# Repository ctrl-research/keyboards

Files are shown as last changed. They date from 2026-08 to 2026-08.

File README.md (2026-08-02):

# keyboards
Schematics, pcbs, layout files for all my keyboard projects

## Structure

- `design/` — original keyboard designs, one folder per board with
  `layout/` (KLE, keymap, VIA), `pcb/` (KiCad), `case/` (3DP CAD), and
  `firmware/` (QMK/VIA builds) inside
  - [`gemini/`](design/gemini/) — split staggered 40% that docks into a regular 40%
- `commissions/` — VIA/layout files for boards built for others
- `docs/` — GitHub Pages site with interactive design docs, deployed by
  [`.github/workflows/pages.yml`](.github/workflows/pages.yml) on every push
  to `main` that touches `docs/` (one-time setup: Settings → Pages → Source →
  GitHub Actions)

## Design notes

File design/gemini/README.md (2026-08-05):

# Gemini

A split, row-staggered 40% whose two halves dock together to form a regular
staggered 40%. Two boards, one keyboard — hence Gemini (and it's a *mini*).

## Concept

- One Raspberry Pi Pico drives the whole board from the left half; the right
  half is passive (I/O expander) and links over a USB-C cable carrying I2C.
- Apart: a classic two-piece ergo split you can tent and shoulder-width.
- Docked: the halves mate along a staggered seam and become a conventional
  12.75u × 4u 40% (MiniVan-class footprint), visually indistinguishable from a
  one-piece board.
- The row stagger is the joint: the seam steps rightward as it descends, so the
  halves interlock like puzzle pieces instead of meeting at a straight line.

## Docked layout (12.75u × 4u)

```
|Tab  | Q | W | E | R | T ‖ Y | U | I | O | P | Bksp |
|Ctrl  | A | S | D | F | G ‖ H | J | K | L | ; | Ent |
|Shift   | Z | X | C | V | B ‖ N | M | , | . | Shift  |
|Ctl |Gui|Alt |   Space    ‖   Space   | Fn | Alt |Ctl|
```

`‖` marks the seam. Widths are approximate above; exact geometry below.

### Row geometry (units of u, x measured from left edge)

| Row | Left half | Seam x | Right half |
|-----|---|---|---|
| 1 | Tab 1.25 · Q W E R T (5×1u) | 6.25 | Y U I O P (5×1u) · Bksp 1.5 |
| 2 | Ctrl 1.5 · A S D F G (5×1u) | 6.50 | H J K L ; (5×1u) · Enter 1.25 |
| 3 | Shift 1.75 · Z X C V B (5×1u) | 6.75 | N M , . (4×1u) · Shift 2 |
| 4 | Ctrl 1.25 · GUI 1 · Alt 1.25 · Space 2.75  | 6.25 | Space 2.75 · Fn 1.25 · Alt 1.25 · Ctrl 1.25 |

Every row totals 12.75u. Standard row stagger (Tab 1.25 → Ctrl 1.5 → Shift
1.75) so the docked board reads as a normal staggered 40%.

### Seam path

Tracing the boundary of the left half from the top edge down
(coordinates in u, origin at top-left of the docked board):

```
(6.25, 0) → (6.25, 1) → (6.50, 1) → (6.50, 2) → (6.75, 2)
→ (6.75, 3) → (6.25, 3) → (6.25, 4)
```

Rows 1–3 step 0.25u right per row (following the alpha stagger); row 4 steps
back to 6.25 at the split spacebars, giving the right half a 0.5u tooth that
hooks under the left half's row 3 — a natural mechanical interlock.

The PCBs and plates are inset 1.45 mm from this boundary; the **case seam
walls** sit exactly on it and are what actually mate (with embedded
magnets) when the halves dock. See [`case/README.md`](case/README.md).

### Dimensions (1u = 19.05 mm)

| Piece | Width | Depth |
|---|---|---|
| Docked | 12.75u = 242.9 mm | 4u + 8 mm brow = 84.2 mm |
| Left half | 6.25–6.75u = 119.1–128.6 mm | 84.2 mm |
| Right half  | 6.00–6.50u = 114.3–123.8 mm | 84.2 mm |

The 8 mm rear "brow" above row 0 hosts the USB-C link ports (and the
Pico's micro-USB reach); the seam runs straight through it at 6.25u. The
key field itself stays exactly 4u deep.

(Plus case wall thickness on the non-seam edges; the seam faces should sit
flush metal-to-metal / plastic-to-plastic.)

## Split & docking mechanism (proposal)

- **Alignment**: the stepped seam self-aligns in x/y; add 2 press-fit dowel
  pins + receivers on the seam faces for z alignment.
- **Retention**: 4–6 pairs of 5×2 mm neodymium magnets embedded in the seam
  faces (polarity keyed so the halves only mate the correct way).
- **Electrical**:
  - One controller: a Raspberry Pi Pico on the left half (header-mounted on
    the back); the right half is passive with an MCP23017 I/O expander.
  - Halves link over **USB-C carrying I2C** (3V3/SDA/SCL/GND) — any USB 2.0
    C-to-C cable, orientation-proof. Works docked and split.
  - Per-key RGB: south-facing SK6812 MINI-E (reverse-mount), one 43-LED
    chain crossing the link on the cable's CC wire.
  - Stretch goal: spring-loaded pogo pins in the row-2/3 seam faces carrying
    the same signals so docking needs no cable at all.
  - Details: [`pcb/pinmap.md`](pcb/pinmap.md).

## Matrix

Both halves are electrically 4×6 (left scanned by the Pico, right read over
I2C via the expander):

| Half  | R1 | R2 | R3 | R4 |
|---|---|---|---|---|
| Left  | 6 keys | 6 keys | 6 keys | 4 keys (2 cols unused) |
| Right | 6 keys | 6 keys | 5 keys | 4 keys |

## Default keymap

See [`layout/keymap.md`](layout/keymap.md) — Base + Raise (hold right `Fn`)
+ Lower (hold left `Space`) + Adjust, MiniVan conventions, vim arrows on
`HJKL`, full 104-key coverage.

## Keycap compatibility

All sizes are standard: 1u, 1.25u, 1.5u, 1.75u, 2u, 2.75u. Notes:

- 2.75u "spacebars" are usually sold as right-Shift caps — fine in uniform
  profiles (DSA/XDA/KAT uniform); sculpted sets will have R2 shift profile.
- 1.25u Enter is a standard size but a rare legend; blanks or novelty caps.

## Project structure

- [`layout/`](layout/) — KLE layouts (docked + split, importable at
  keyboard-layout-editor.com) and the default keymap layer maps; VIA
  definition lands here too.
- [`pcb/`](pcb/) — KiCad projects for both halves.
- [`case/`](case/) — 3D-printed case CAD + STL/STEP exports.
- [`firmware/`](firmware/) — QMK keyboard definition, VIA support, built
  `.uf2` images.

## Open questions

- [ ] Split space sizes: 2.75/2.75 as drawn, or asymmetric (e.g. 2.25 + Fn on
      left thumb) for a dedicated layer key on the seam?
- [ ] Right Shift 2u vs. 1u Shift + dedicated `/` or `↑`?
- [ ] Pogo pins vs. cable-only for docked mode?
- [ ] Rotary encoder in place of a 1u mod on each half?
- [ ] Case: tray-mount 3DP first article, then CNC alu gasket for v2?

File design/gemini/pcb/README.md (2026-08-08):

# pcb

KiCad projects for the Gemini PCBs — one board per half.

**Architecture (rev A): one controller.** A single Raspberry Pi Pico on the
left half (header-mounted on the back, ~2.5 mm standoff); the right half is
passive with an MCP23017 I/O expander. The halves link over **USB-C
carrying I2C** (3V3/SDA/SCL/GND — any USB 2.0 C-to-C cable). Full pin map,
link wiring, socket-DNP keys and BOM: [`pinmap.md`](pinmap.md).

## Generated projects

- [`gemini-left/`](gemini-left/), [`gemini-right/`](gemini-right/) —
  generated `.kicad_pcb` per half: all footprints placed, nets assigned,
  seam edge cuts drawn. **Unrouted** — routing is interactive work.
- [`gemini-panel/`](gemini-panel/) — **production panel** for JLCPCB/PCBWay:
  both halves in one board, joined along their straight *outer* edges at
  x = 0 with a single **V-score** snap line (the stepped seam can't be
  V-scored — it faces outward and is routed normally). Refs and nets are
  prefixed `L_`/`R_`. Route the individual halves first, then regenerate —
  or route the panel directly and it supersedes them. When ordering: pick
  "panel by customer", 2 designs, and note "V-cut where marked" in remarks.
  Snapped V-score edges land inside the case (the seam-inset walls cover
  all board edges), so no cosmetic cleanup matters.
- Regenerate with KiCad's bundled python (wx workaround included):

  ```
  /Applications/KiCad/KiCad.app/Contents/Frameworks/Python.framework/Versions/Current/bin/python3 tools/gen_kicad_boards.py
  ```

## Inputs (source of truth: `../layout/gemini_docked.kle.json`)

- [`tools/gen_pcb_data.py`](tools/) — derives everything below from the
  layout geometry; [`tools/gen_kicad_boards.py`](tools/) builds the boards.
- [`placement/*_placement.csv`](placement/) — switch centers in mm with
  matrix row/col (per-half origin at its top-left corner).
- [`placement/*_outline.csv`](placement/) — Edge.Cuts vertices in mm
  including the stepped docking seam (inset 1.45 mm from the key boundary —
  the case seam wall carries the true boundary) and the 8 mm rear brow
  (link ports live there). Left ≤ 127.14 × 84.2 mm, right ≤ 122.38 × 84.2 mm.
- [`kbplacer/*_matrix.kle.json`](kbplacer/) — KLE annotated with `row,col`
  legends for the [kbplacer](https://github.com/adamws/kicad-kbplacer)
  plugin.
- [`lib/gemini.pretty`](lib/) — vendored footprints (marbastlib hotswap +
  stabs, Pico, HRO USB-C, MCP23017/passives from KiCad stock) and 3D
  models; licenses in `lib/licenses/`.
- [`gemini.kicad_mod`](gemini.kicad_mod) — source logo artwork from
  bitmap2component (35.9 × 13.9 mm). [`tools/gen_logo_fp.py`](tools/)
  scales it to 6 mm tall and writes `lib/gemini.pretty/Logo_Gemini.kicad_mod`
  with its origin at the artwork centre; the board generator places that
  on **F.SilkS**, centred in the 8 mm rear brow (left x 58.81, right
  x 62.29, both at y −4). The brow's *back* face is full of ports and
  passives, so the front face is where the room is. 6 mm is the practical
  floor for the small "by: j6n" glyphs: it keeps the thinnest stroke at
  0.40 mm and the tightest enclosed counter at 0.22 mm, versus the
  0.15 mm silkscreen minimum JLCPCB/PCBWay quote.

## 3D exports

The docs page's **3D model tab** (`docs/gemini/#model`) renders the full
assembly — boards + case pieces, docked/split and exploded/assembled
(three.js; GLBs live in `docs/gemini/3d/`). Re-export after board changes:

```
kicad-cli pcb export glb --subst-models --include-tracks --include-pads \
  --include-zones --include-silkscreen --user-origin 119.0625x0mm \
  -o raw-left.glb gemini-left/gemini-left.kicad_pcb   # right: no origin arg
npx gltfpack -i raw-left.glb -o docs/gemini/3d/gemini-left.glb -cc -mi -si 0.4 -noq
```

(The +119.0625 mm origin shift puts both halves in one docked frame.
`-noq` matters: quantized output renders at the wrong scale in the viewer.
`--include-silkscreen` costs ~4 % file size and is what makes the brow
logo and the reference designators show up in the viewer.)

## Before fab (rev A checklist)

- [x] Route both boards (autorouted + USB-C escapes rebuilt by hand: the
      generated nested stitch fenced the inner nets on B.Cu, so each link
      /host connector now fans out through 0.6/0.3 vias to F.Cu; DRC: 0
      unconnected on both halves and the panel)
- [ ] Verify HRO USB-C pad↔pin mapping against the datasheet (incl. which
      pads are CC vs SBU — the LED chain crosses on CC)
- [ ] Verify SK6812 MINI-E pad order (assumed 1=VDD 2=DOUT 3=VSS 4=DIN)
- [ ] Host port TP1/TP2 pads: bridge to Pico underside TP3 (D+) / TP2 (D−)
      — decide jumper wires vs relocating pads under the TPs for spring pins
- [ ] Series resistors on link D± so a real charger/host can't hurt anything
- [ ] QMK: cap `RGB_MATRIX_MAXIMUM_BRIGHTNESS` (~120) — 43 LEDs at full
      white would far exceed a 500 mA USB 2.0 budget
- [ ] DRC: Pico pin rows sit at y=19.7 and y=37.5, in the corridors between
      switch rows on both faces — confirm clearances after any nudges
- [ ] Confirm J1 orientation (port opening must overhang the rear edge)
- [ ] Case: ~5 mm pocket under the Pico strip (~2 mm elsewhere), rear
      cutouts for both link ports, side cutout for the Pico micro-USB

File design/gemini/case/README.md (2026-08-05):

# case

3D-printable case for both halves — three pieces per half, generated
parametrically by [`tools/gen_case.py`](tools/) (CadQuery) from the same
outline/placement CSVs as the PCBs.

## Stack-up (z from interior floor, per half)

| z (mm) | What |
|---|---|
| −3.0 … 0 | bottom case floor |
| 0 … 5.5 | component space (sockets 1.85, Pico stack ≈ 4.5) |
| 6.0 … 7.6 | PCB (floats — gasket mount, nothing screws into it) |
| 10.1 | lower gasket ledge (bottom case) |
| 11.1 … 12.6 | switch plate (1.5 mm), flange rides the gaskets |
| 11.8 | bottom-case rim / top-case joint line |
| 14.0 | upper gasket press lip (top case underside) |
| 16.5 | top-case bezel top (caps bottom out ≈ 18) |

Gasket: 1.5 mm poron strips above and below the plate's 2.5 mm perimeter
flange, on all edges **except the seam edge**.

## The seam edge (docking side)

The PCB and plate stop **1.45 mm short** of the true key-boundary seam
(`SEAM_INSET_MM` in `pcb/tools/gen_pcb_data.py`), which buys room for a
proper case wall on the joining side:

- **Bottom case**: full-height 1.2 mm seam wall whose *outer face sits
  exactly on the boundary* — the case walls, not the board edges, carry the
  stepped interlock and are what touch when docked. Below z = 4 the wall
  thickens inward to 2.45 mm to hold 4 × Ø3×2 mm magnet pockets (axis
  horizontal, z = 2); positions mirror across halves, polarity alternates
  N/S so the halves only dock in the correct alignment.
- **Plate and PCB**: recessed 1.45 mm behind the seam wall, fully covered
  from the side. No gasket on this edge (the plate flange stops).
- **Top case**: still open above the rim on the seam side of the key field
  (pressed caps sweep that space), but its rear band roofs the brow all the
  way to the seam plane — the two brow roofs meet when docked.

Docked appearance: caps keep near-normal spacing; beneath them the two
seam walls meet as a clean stepped line, ~2.4 mm of case material total.

## Pieces (× left/right)

1. **`*_bottom.stl/.step`** — floor + walls, gasket ledge, magnet pockets,
   port cutouts (host USB-C at left-rear corner L, link USB-C at seam-rear
   corner both halves, micro-USB side cutout L), BOOTSEL finger hole in the
   floor (L), M2 screw pilot bores in the wall tops.
2. **`*_plate.stl/.step`** — gasket-mount plate engineered against
   print-curl (see below): 1.5 mm clip web + 1.2 mm stiffening skirt
   (2.7 mm total), MX cutouts, stab cutouts, perimeter flange (1.5 mm, so
   the gasket stack is unchanged) with notches at the screw columns. Or fab
   flat 1.5 mm FR4/POM/alu from the STEP's top web.
3. **`*_top.stl/.step`** — bezel frame: presses the upper gaskets via its
   inner lip, slim ~2.9 mm bezel, counterbored M2 screws (4/half) from the
   top into the bottom-case wall pilots.

## Fasteners & hardware (per keyboard)

| Qty | Part |
|-----|---|
| 8 | M2 × 12 screw (top → bottom wall) |
| 8 | Ø3 × 2 mm neodymium magnet (seam, glued, alternating polarity) |
| ~1 m| 1.5 mm poron gasket strip |

## Printed plates and curl

A thin printed plate bows upward days after switches go in: every MX
switch's clips push outward on their cutout continuously, and 40+ switches
of sustained stress creep a 1.5 mm printed plate into a banana — PLA is the
worst offender. Countermeasures baked into the generator:

- **Clip web + skirt**: MX clips need exactly 1.5 mm of material to latch,
  so the plate keeps a 1.5 mm top web at nominal cutout size, backed by a
  1.2 mm skirt whose openings are relieved to 15.5 mm (clips and housing
  never touch it). ~2.7 mm effective thickness ≈ 6× the bending stiffness
  of a bare 1.5 mm plate, with zero change to how switches seat.
- **Fit tolerance**: `sw_cut` defaults to 14.2 mm because FDM holes print
  undersize. **Print `stl/plate_fit_coupon.stl` first** (three cutouts:
  14.1 / 14.2 / 14.3, engraved) in your actual plate material and
  orientation. Pick the size where a switch clicks in and holds without
  forcing — a too-tight fit is exactly what stores the curling stress. Set
  `P["sw_cut"]`, regenerate.
- **Material**: PETG minimum; ASA/ABS or PC better (higher creep
  resistance). Avoid PLA for the plate. Print flat, 5+ perimeters or 100%
  infill.

## Regenerate

```
cd design/gemini/case
.venv/bin/python tools/gen_case.py     # venv: python3.12 -m venv .venv && .venv/bin/pip install cadquery
```

## Known v0.1 limitations (iterate before committing to a print)

- Stab cutouts are simplified rectangles — replace with proper Cherry
  plate-mount profiles before a metal plate order.
- BOOTSEL hole position is approximate (module-center offset); verify
  against a real Pico.
- No dowel pins yet — magnets + the stepped-seam interlock handle alignment.
- Tenting/feet, bumpon recesses, and the docked-mode pogo idea are future.

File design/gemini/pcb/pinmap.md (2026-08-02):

# Gemini — electronics & pin map (rev A)

**One controller.** A single Raspberry Pi Pico on the **left** half; the
right half is passive with an **MCP23017 I/O expander**. The halves link
over **USB-C carrying I2C** — 4 conductors (3V3 on VBUS, SDA on D+, SCL on
D−, GND), so any USB 2.0 C-to-C cable works and orientation doesn't matter.
No split-sync firmware: the whole keyboard is one matrix, half of it read
over I2C (ErgoDox-style; QMK supports expander matrices natively).

## Left half — Raspberry Pi Pico (U1)

On the back, **horizontal, centered on the row-1 switch centerline**
(y = 28.575 mm), micro-USB (host port) exiting the **outer-left side
edge**. Its two header pin rows land at y ≈ 19.7 and 37.5 mm — near the
centers of the top-face corridors between switch housings, so the pins
protruding through the board clear the switch bodies sitting on top, and
no through-hole touches any socket pad or switch drill. Two row-1 diodes
(D10, D11) relocate into the brow to stay off the lower pin row.
**Mounted on low-profile headers (~2.5 mm standoff), not flat**: switch
pins protrude ~1.7 mm below the PCB and hotswap sockets are 1.85 mm tall,
so both clear underneath the module — every key above the Pico keeps its
hotswap socket. The case gets a ~5 mm pocket along this strip (elsewhere
~2 mm suffices) and a side cutout for the micro-USB.

| Pico pin | GPIO | Function | Notes |
|---|---|---|---|
| 1 | GP0 | I2C0 SDA | to link port D+ · 4.7 kΩ pull-up (R1) |
| 2 | GP1 | I2C0 SCL | to link port D− · 4.7 kΩ pull-up (R2) |
| 4–7 | GP2–GP5  | ROW0–ROW3 | shared row nets, left matrix |
| 9–12, 14–15 | GP6–GP11 | COL0–COL5 | left matrix (pin 13 is GND) |
| 21 | GP16 | LED data | → 74AHCT1G125 (U2) → LED chain |
| 36 | 3V3 | Logic rail | I2C pull-ups |
| 40 | VBUS | +5V | LED power + right half via link|
| 3, 8, 13, … | GND | Ground | |

Unused GPIOs break out to labeled test pads (encoder, pogo dock
detect — future).

## Host USB-C port (J2, left half, outer-left corner of the brow)

The desk-cable port, at the board's top-left corner — the link port sits at
the opposite (seam) end of the brow. Alternative to the Pico's onboard
micro-USB (mid-board at the side edge — flash/debug fallback). Proper
device-role port:

- **CC1/CC2**: separate 5.1 kΩ pulldowns (R3/R4) so C-to-C cables and hosts
  supply VBUS.
- **VBUS → VSYS** through Schottky DV1 (B5819W), diode-ORed against the
  Pico's internal VBUS→VSYS diode — safe with both cables plugged, per the
  Pico datasheet's dual-power pattern.
- **D+/D−**: the Pico exposes USB data only on underside test points, not
  the header. J2's D± route to two pads (TP1/TP2) in the brow next to the
  module's USB end — bridge to the Pico's **TP3 (D+) / TP2 (D−)** with two
  short jumper wires at assembly (or relocate the pads under the exact TP
  positions for spring pins during routing).
- Everything downstream (LEDs, link, right half) runs off **VSYS**
  (~4.7 V after the diode) — works identically from either port.

## Right half — MCP23017-E/SO (U1, SOIC-28)

| MCP pin | Signal | Function |
|---|---|---|
| 1–6 | GPB0–GPB5| COL0–COL5 (right) |
| 21–24 | GPA0–GPA3| ROW0–ROW3 (right) |
| 9 / 10  | VDD / VSS| 3V3 (from link) / GND · 100 nF (C1) |
| 12 / 13 | SCL / SDA| I2C, address 0x20 |
| 15–17 | A0–A2 | tied GND |
| 18 | /RESET | tied 3V3 |

3V3 comes from a local **MCP1700-3302** LDO (U2) fed by the 5V link, with
1 µF caps on both sides (C2/C3).

## Link port (J1 on each half — HRO TYPE-C-31-M-12)

| USB-C pins | Net | Carries |
|---|---|---|
| GND (1/12/shield) | GND | ground |
| VBUS (2/11) | +5V | power to right half + LEDs |
| D+ (A6/B6 = 6/7)  | SDA | I2C data |
| D− (A7/B7 = 5/8)  | SCL | I2C clock |
| CC + SBU (3/4/9/10) | LED_LINK | WS2812 LED chain data  |

CC1/CC2 are tied together on each board so the cable's single CC wire
carries LED data regardless of plug orientation (SBUs tied too — unwired
in USB 2.0 cables, parallel in full-featured ones, harmless either way).
⚠ **Requires a basic non-e-marked C-to-C cable** — an e-marker chip loads
the CC line. ⚠ **Not a real USB port** — label it. Verify the pad↔pin
mapping against the HRO datasheet before fab. Consider series resistors on
D± so nothing dies if someone plugs in a charger.

## Per-key RGB (south-facing)

**SK6812 MINI-E** reverse-mount, one per key, on the back at the switch's
**south LED window** (key center +5.08 mm) shining up through a plated
cutout — south-facing, so no north-facing keycap interference. Chain:
GP16 → 74AHCT1G125 level shifter (3V3→5V, U2 left) → left 22 LEDs
(row-major) → link CC wire → right 21 LEDs. One 43-LED chain in firmware —
no split RGB sync. Power: 5V from Pico VBUS; **cap brightness in QMK**
(43 × ~60 mA at full white ≈ 2.6 A — far beyond a USB 2.0 port's 500 mA;
`RGB_MATRIX_MAXIMUM_BRIGHTNESS` ≈ 120 keeps worst-case near spec).

## Matrix (COL2ROW, 1N4148W SOD-123 per key)

Left 4×6 (22 keys), right 4×6 (21 keys). Diode cathode → row.
Assignments in `kbplacer/gemini_{left,right}_matrix.kle.json`; switch
centers in `placement/`.

## Hotswap coverage

**All 43 keys are hotswap.** The link USB-C connectors live in an 8 mm rear
"brow" strip above row 0 (board depth 84.2 mm total), clear of every socket
zone; the keys above the header-mounted Pico keep their sockets thanks to
the standoff (see above).

## BOM sketch (per keyboard)

| Qty | Part |
|-----|---|
| 1 | Raspberry Pi Pico + low-profile headers  |
| 1 | MCP23017-E/SO (SOIC-28) |
| 1 | 74AHCT1G125 SOT-23-5 (LED level shift) |
| 1 | MCP1700-3302 SOT-23 (right 3V3 LDO) |
| 1 | B5819W SOD-123 Schottky (host VBUS OR) |
| 3 | HRO TYPE-C-31-M-12 USB-C receptacle |
| 2 | 5.1 kΩ 0603 (host port CC pulldowns) |
| 43  | SK6812 MINI-E (reverse mount RGB) |
| 43  | 1N4148W SOD-123 |
| 43  | Kailh MX hotswap socket |
| 2 | 4.7 kΩ 0603 (I2C pull-ups, left) |
| 1 | 100 nF 0603 + 2 × 1 µF 0603 |
| 1 | USB 2.0 C-to-C cable (link, non-e-marked)|
| 8–12| 5×2 mm neodymium magnets (case) |
| — | M2 heat-set inserts + screws (case) |

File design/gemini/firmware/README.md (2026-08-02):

# firmware

QMK keyboard definition and VIA support for Gemini.

Planned contents:

- `qmk/` — keyboard definition (`keyboard.json`, split config, default keymap
  per [`../layout/keymap.md`](../layout/keymap.md))
- `via/` — VIA definition JSON (same format as `commissions/*` files)
- Prebuilt `.uf2` per tagged release

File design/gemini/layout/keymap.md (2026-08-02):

# Gemini — default keymap (draft 2)

Design goal: **every key on a full-size (104-key) keyboard is typeable**,
and the common ones fall in comfortable places. This is the recommended
default — once the board runs QMK/VIA every layer is user-remappable.

Four layers:

| Layer  | Activation | Contents |
|---|---|---|
| Base | — | alphas, core punctuation, mods |
| Raise  | hold right `Fn` | digits, symbols, arrows, Del |
| Lower  | hold left `Space` | F-keys, nav, media, PrtSc cluster |
| Adjust | hold both (`Fn` + left `Space`) | numpad, RGB, bootloader |

Dual-role keys (QMK mod-tap / layer-tap):

| Key (base position) | Tap | Hold |
|---|---|---|
| R2 leftmost | Esc | Ctrl |
| Left Space (2.75u) | Space | Lower |
| Right `Fn` (1.25u) | — | Raise |

## Base

```
| Tab  | Q | W | E | R | T ‖ Y | U | I | O | P | Bksp |
| Esc⌃ | A | S | D | F | G ‖ H | J | K | L | ; | Ent  |
| Shift  | Z | X | C | V | B ‖ N | M | , | . | Shift |
| Ctl |Gui|Alt |  Spc/Lwr  ‖   Space  | Fn | Alt |Ctl |
```

## Raise (hold `Fn`) — digits, symbols, arrows

```
|  `   | 1 | 2 | 3 | 4 | 5 ‖ 6 | 7 | 8 | 9 | 0 | Del |
| Ctrl | - | = | [ | ] | \ ‖ ← | ↓ | ↑ | → | ' | Ent |
| Shift  |   |   |   |   |  ‖   |   |   | / | Shift |
| Ctl |Gui|Alt |   Space   ‖   Space  |(Fn)| Alt |Ctl |
```

- Digits mirror the standard number-row split (1–5 left, 6–0 right).
- Arrows vim-style on `HJKL`; `'` stays on the pinky where a 60% has it.
- `/` on `.` — so `?` is naturally `Raise+Shift+.`.
- Symbols `-=[]\` on the left home row in number-row order.

## Lower (hold left `Space`) — F-keys, nav, media

```
| F12  |F1 |F2 |F3 |F4 |F5 ‖ F6 | F7 | F8 | F9 |F10| F11 |
| Caps |Ins|PSc|SLk|Pse|   ‖ Hom|PgD |PgU |End |   | Ent  |
| Shift  |   |   |   |   |  ‖ Prv|Vo- |Vo+ |Nxt | Play  |
| Ctl |Gui|Alt | (held)    ‖   Space  | App|RGui|Ctl |
```

- F1–F10 mirror the digit positions; F11/F12 close the row ends.
- Nav cluster (Home/PgDn/PgUp/End) sits under the Raise arrows — same
  fingers, one layer over.
- Ins / PrtSc / ScrLk / Pause across the left home row.
- `App` (menu) and right `GUI` on the right thumb keys.

## Adjust (hold `Fn` + left `Space`) — numpad, board controls

```
| Boot |RGB|Hue|Sat|Val|   ‖NmLk| P7 | P8 | P9 | P- | Del  |
| Ctrl |   |   |   |   |   ‖ P/ | P4 | P5 | P6 | P+ | PEnt |
| Shift  |   |   |   |   |  ‖ P* | P1 | P2 | P3 | Shift |
| Ctl |Gui|Alt | (held)    ‖    P0    |(Fn)| P. |Ctl |
```

- Numpad digits as a 3×3 grid on `UIO`/`JKL`/`M,.` matching a real numpad;
  `P0` big on the right spacebar, `P.` beside it.
- `Boot` = QK_BOOT (flash mode) — needs three keys held plus the far
  corner, effectively impossible to hit by accident.

## Coverage audit — full-size (104-key) parity

| Full-size key group | Where it lives on Gemini |
|---|---|
| A–Z, `,` `.` `;`, Tab, Enter, Space | Base |
| Shift ×2, Ctrl ×2, Alt ×2, GUI (L) | Base |
| Esc | Base (tap of Esc/Ctrl) |
| 1–0, `` ` `` `-` `=` `[` `]` `\` `'` `/`| Raise |
| Arrows, Delete | Raise |
| F1–F12, Caps Lock | Lower |
| Ins, PrtSc, ScrLk, Pause | Lower |
| Home, End, PgUp, PgDn | Lower |
| App/Menu, GUI (R) | Lower |
| Numpad 0–9, `.` `/` `*` `-` `+`, Enter  | Adjust |
| Num Lock | Adjust |
| Media (not on 104, bonus) | Lower |

Every 104-key legend is reachable; nothing requires more than two held
keys (Adjust = both thumbs, then the target).

## Open items

- [ ] Left-hand-only shortcuts layer for mouse-in-right-hand use?
- [ ] Home-row mods as an alternate keymap once the board exists — easy to
      A/B in firmware, no hardware impact.
- [ ] Split-mode niceties: swap which thumb triggers Raise/Lower per user
      preference in VIA.

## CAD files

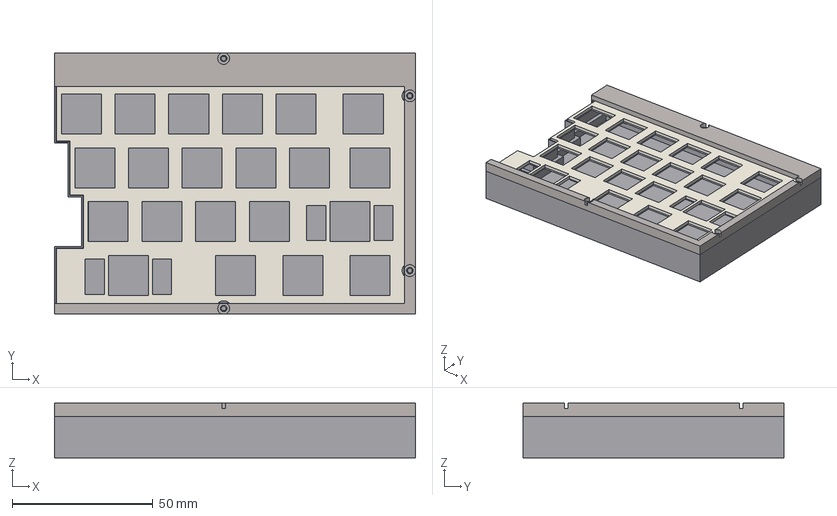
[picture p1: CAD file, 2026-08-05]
design/gemini/case/step/gemini_right_assembly.step
128.1 x 92.7 x 19.5 mm
bottom
plate
top

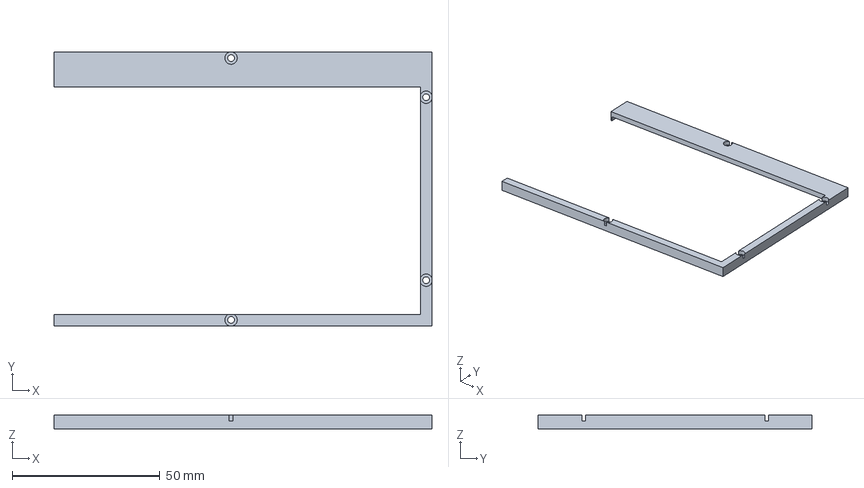
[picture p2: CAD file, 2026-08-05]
design/gemini/case/step/gemini_right_top.step
128.1 x 92.7 x 4.70 mm

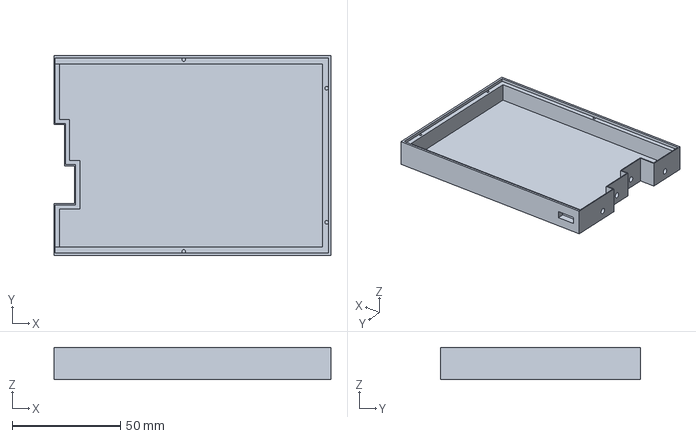
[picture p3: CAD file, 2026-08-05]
design/gemini/case/step/gemini_right_bottom.step
128.1 x 92.7 x 14.8 mm

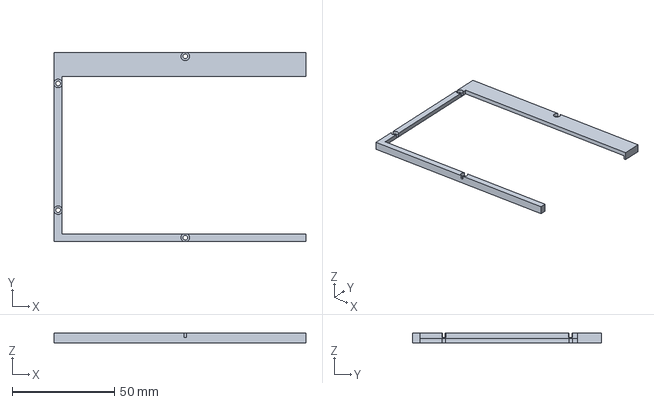
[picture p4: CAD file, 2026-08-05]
design/gemini/case/step/gemini_left_top.step
123.3 x 92.7 x 4.70 mm

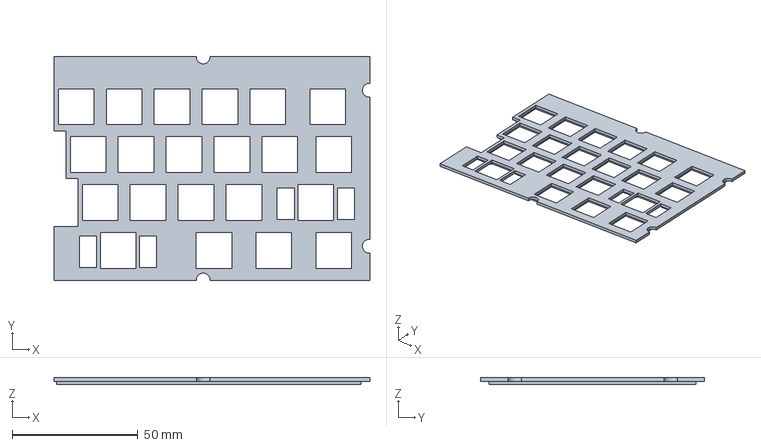
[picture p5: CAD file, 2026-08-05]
design/gemini/case/step/gemini_right_plate.step
125.6 x 89.2 x 2.70 mm

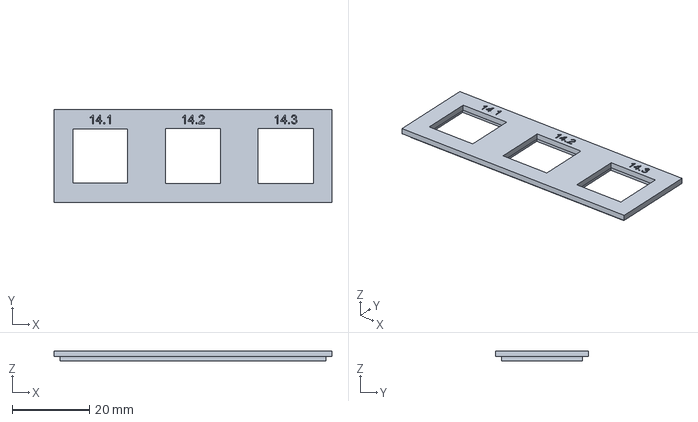
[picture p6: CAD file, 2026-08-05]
design/gemini/case/step/plate_fit_coupon.step
72.0 x 24.0 x 2.70 mm

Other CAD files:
design/gemini/case/step/gemini_left_assembly.step
design/gemini/case/step/gemini_left_plate.step
design/gemini/case/step/gemini_left_bottom.step
design/gemini/case/stl/gemini_left_bottom.stl
design/gemini/case/stl/gemini_left_plate.stl
design/gemini/case/stl/gemini_left_top.stl
design/gemini/case/stl/gemini_right_bottom.stl
design/gemini/case/stl/gemini_right_plate.stl
design/gemini/case/stl/gemini_right_top.stl
design/gemini/case/stl/plate_fit_coupon.stl

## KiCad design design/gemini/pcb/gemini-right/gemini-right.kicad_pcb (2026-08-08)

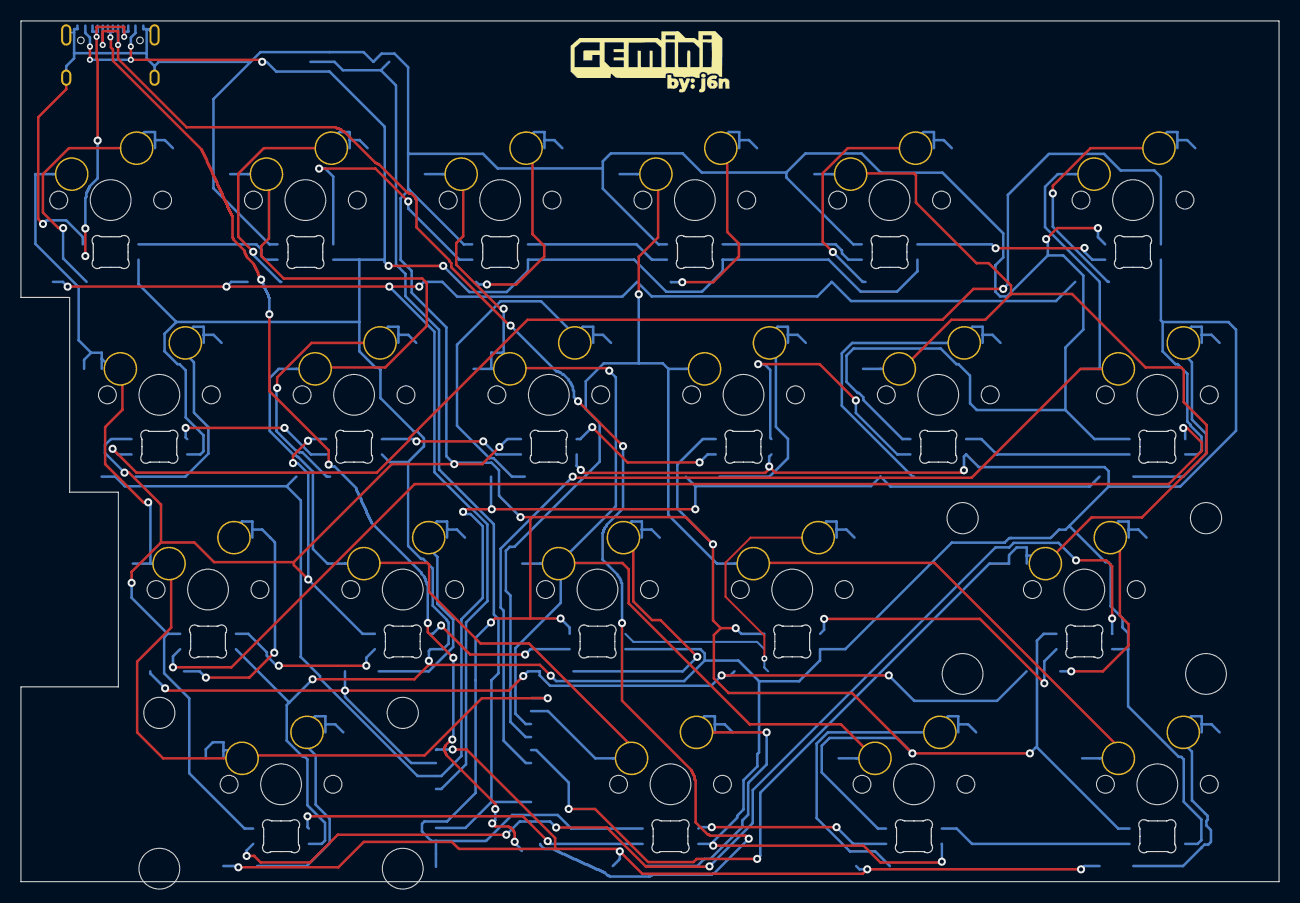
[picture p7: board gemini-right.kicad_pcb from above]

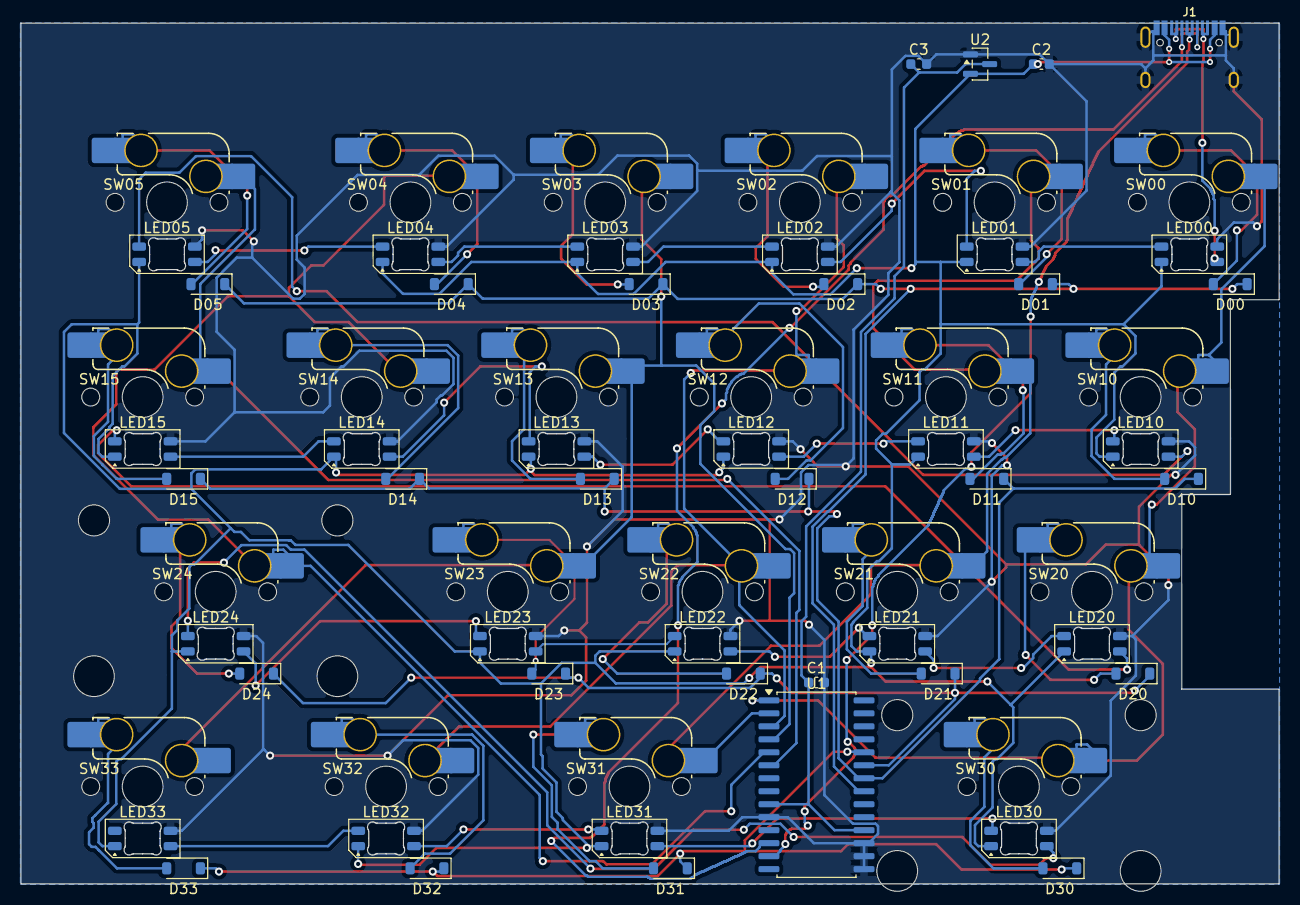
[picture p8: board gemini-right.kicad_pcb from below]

Board: 2 copper layers, 123.1 x 84.2 mm, 72 parts (69 on the bottom side), 57 nets.

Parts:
C1: 100nF; C_0603_1608Metric
C2, C3: 1uF; C_0603_1608Metric
D00, D01, D02, D03, D04, D05, D10, D11, D12, D13, D14, D15, D20, D21, D22, D23, D24, D30, D31, D32, D33: 1N4148W; D_SOD-123
G1: Logo_Gemini
J1: USB-C link; HRO-TYPE-C-31-M-12-Assembly
LED00, LED01, LED02, LED03, LED04, LED05, LED10, LED11, LED12, LED13, LED14, LED15, LED20, LED21, LED22, LED23, LED24, LED30, LED31, LED32, LED33: SK6812MINI-E; LED_SK6812MINI-E_3.2x2.8mm_P1.5mm_ReverseMount
ST_SW24: stab 2.0u; STAB_MX_2u
ST_SW30: stab 2.75u; STAB_MX_2.75u
SW00: Y; SW_MX_HS_CPG151101S11_1u
SW01: U; SW_MX_HS_CPG151101S11_1u
SW02: I; SW_MX_HS_CPG151101S11_1u
SW03: O; SW_MX_HS_CPG151101S11_1u
SW04: P; SW_MX_HS_CPG151101S11_1u
SW05: Bksp; SW_MX_HS_CPG151101S11_1.5u
SW10: H; SW_MX_HS_CPG151101S11_1u
SW11: J; SW_MX_HS_CPG151101S11_1u
SW12: K; SW_MX_HS_CPG151101S11_1u
SW13: L; SW_MX_HS_CPG151101S11_1u
SW14: ;; SW_MX_HS_CPG151101S11_1u
SW15: Enter; SW_MX_HS_CPG151101S11_1.25u
SW20: N; SW_MX_HS_CPG151101S11_1u
SW21: M; SW_MX_HS_CPG151101S11_1u
SW22: ,; SW_MX_HS_CPG151101S11_1u
SW23: .; SW_MX_HS_CPG151101S11_1u
SW24: Shift; SW_MX_HS_CPG151101S11_1u
SW30: Space; SW_MX_HS_CPG151101S11_1u
SW31: Fn; SW_MX_HS_CPG151101S11_1.25u
SW32: Alt; SW_MX_HS_CPG151101S11_1.25u
SW33: Ctrl; SW_MX_HS_CPG151101S11_1.25u
U1: MCP23017-E/SO; SOIC-28W_7.5x17.9mm_P1.27mm
U2: MCP1700-3302; SOT-23

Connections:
+3V3: C1.1, C3.1, U1.9, U1.18, U2.3
COL0: SW00.1, SW10.1, SW20.1, SW30.1, U1.1
COL1: SW01.1, SW11.1, SW21.1, SW31.1, U1.2
COL2: SW02.1, SW12.1, SW22.1, SW32.1, U1.3
COL3: SW03.1, SW13.1, SW23.1, SW33.1, U1.4
COL4: SW04.1, SW14.1, SW24.1, U1.5
COL5: SW05.1, SW15.1, U1.6
GND: C1.2, C2.2, C3.2, J1.1, J1.12, J1.13, LED00.3, LED01.3, LED02.3, LED03.3, LED04.3, LED05.3, LED10.3, LED11.3, LED12.3, LED13.3, LED14.3, LED15.3, LED20.3, LED21.3, LED22.3, LED23.3, LED24.3, LED30.3, LED31.3, LED32.3, LED33.3, U1.10, U1.15, U1.16, U1.17, U2.1
LED_CH01: LED00.2, LED01.4
LED_CH02: LED01.2, LED02.4
LED_CH03: LED02.2, LED03.4
LED_CH04: LED03.2, LED04.4
LED_CH05: LED04.2, LED05.4
LED_CH06: LED05.2, LED10.4
LED_CH07: LED10.2, LED11.4
LED_CH08: LED11.2, LED12.4
LED_CH09: LED12.2, LED13.4
LED_CH10: LED13.2, LED14.4
LED_CH11: LED14.2, LED15.4
LED_CH12: LED15.2, LED20.4
LED_CH13: LED20.2, LED21.4
LED_CH14: LED21.2, LED22.4
LED_CH15: LED22.2, LED23.4
LED_CH16: LED23.2, LED24.4
LED_CH17: LED24.2, LED30.4
LED_CH18: LED30.2, LED31.4
LED_CH19: LED31.2, LED32.4
LED_CH20: LED32.2, LED33.4
LED_LINK: J1.3, J1.4, J1.9, J1.10, LED00.4
N_SW00: D00.2, SW00.2
N_SW01: D01.2, SW01.2
N_SW02: D02.2, SW02.2
N_SW03: D03.2, SW03.2
N_SW04: D04.2, SW04.2
N_SW05: D05.2, SW05.2
N_SW10: D10.2, SW10.2
N_SW11: D11.2, SW11.2
N_SW12: D12.2, SW12.2
N_SW13: D13.2, SW13.2
N_SW14: D14.2, SW14.2
N_SW15: D15.2, SW15.2
N_SW20: D20.2, SW20.2
N_SW21: D21.2, SW21.2
N_SW22: D22.2, SW22.2
N_SW23: D23.2, SW23.2
N_SW24: D24.2, SW24.2
N_SW30: D30.2, SW30.2
N_SW31: D31.2, SW31.2
N_SW32: D32.2, SW32.2
N_SW33: D33.2, SW33.2
ROW0: D00.1, D01.1, D02.1, D03.1, D04.1, D05.1, U1.21
ROW1: D10.1, D11.1, D12.1, D13.1, D14.1, D15.1, U1.22
ROW2: D20.1, D21.1, D22.1, D23.1, D24.1, U1.23
ROW3: D30.1, D31.1, D32.1, D33.1, U1.24
SCL: J1.5, J1.8, U1.12
SDA: J1.6, J1.7, U1.13
VSYS: C2.1, J1.2, J1.11, LED00.1, LED01.1, LED02.1, LED03.1, LED04.1, LED05.1, LED10.1, LED11.1, LED12.1, LED13.1, LED14.1, LED15.1, LED20.1, LED21.1, LED22.1, LED23.1, LED24.1, LED30.1, LED31.1, LED32.1, LED33.1, U2.2

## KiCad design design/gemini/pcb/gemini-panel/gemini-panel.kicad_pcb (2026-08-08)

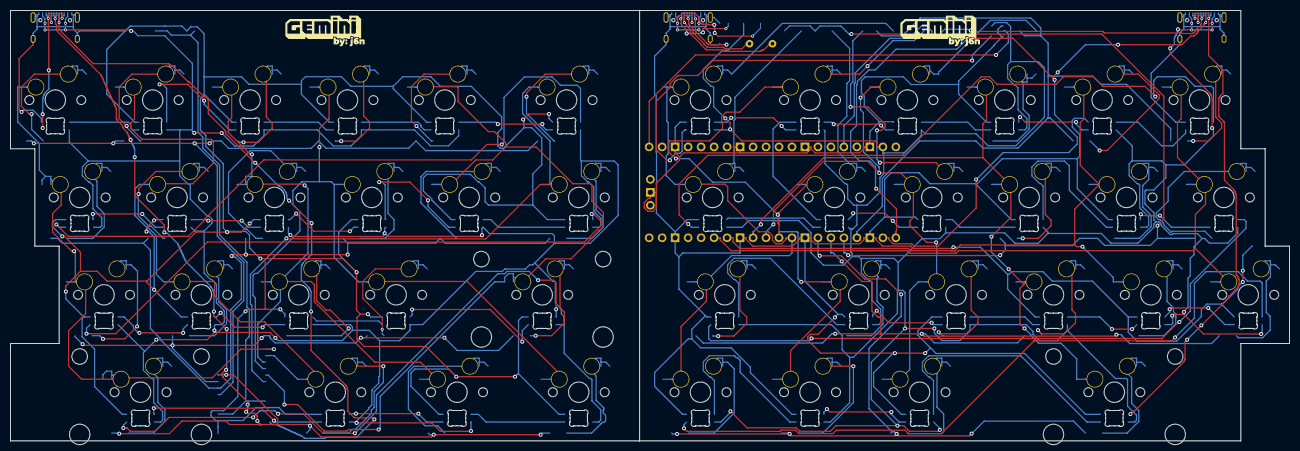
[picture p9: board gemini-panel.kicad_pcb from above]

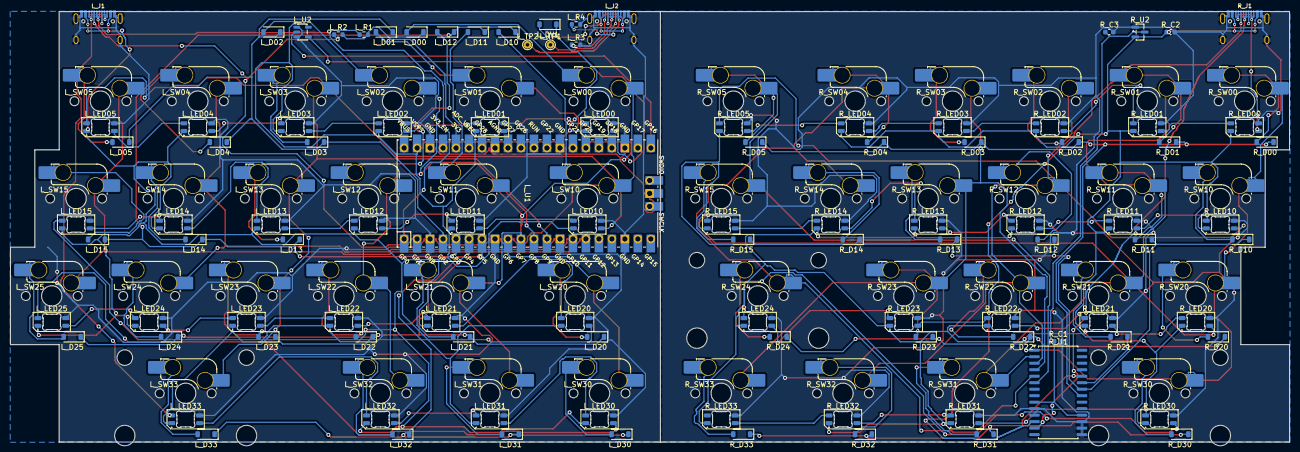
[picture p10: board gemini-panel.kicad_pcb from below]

Board: 2 copper layers, 250.2 x 84.2 mm, 151 parts (146 on the bottom side), 123 nets.

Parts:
L_D00, L_D01, L_D02, L_D03, L_D04, L_D05, L_D10, L_D11, L_D12, L_D13, L_D14, L_D15, L_D20, L_D21, L_D22, L_D23, L_D24, L_D25, L_D30, L_D31, L_D32, L_D33: 1N4148W; D_SOD-123
L_DV1: B5819W; D_SOD-123
L_G1: Logo_Gemini
L_J1: USB-C link; HRO-TYPE-C-31-M-12-Assembly
L_J2: USB-C host; HRO-TYPE-C-31-M-12-Assembly
L_LED00, L_LED01, L_LED02, L_LED03, L_LED04, L_LED05, L_LED10, L_LED11, L_LED12, L_LED13, L_LED14, L_LED15, L_LED20, L_LED21, L_LED22, L_LED23, L_LED24, L_LED25, L_LED30, L_LED31, L_LED32, L_LED33: SK6812MINI-E; LED_SK6812MINI-E_3.2x2.8mm_P1.5mm_ReverseMount
L_R1, L_R2: 4k7; R_0603_1608Metric
L_R3, L_R4: 5k1; R_0603_1608Metric
L_ST_SW33: stab 2.75u; STAB_MX_2.75u
L_SW00: Tab; SW_MX_HS_CPG151101S11_1.25u
L_SW01: Q; SW_MX_HS_CPG151101S11_1u
L_SW02: W; SW_MX_HS_CPG151101S11_1u
L_SW03: E; SW_MX_HS_CPG151101S11_1u
L_SW04: R; SW_MX_HS_CPG151101S11_1u
L_SW05: T; SW_MX_HS_CPG151101S11_1u
L_SW10: Esc/Ctrl; SW_MX_HS_CPG151101S11_1.5u
L_SW11: A; SW_MX_HS_CPG151101S11_1u
L_SW12: S; SW_MX_HS_CPG151101S11_1u
L_SW13: D; SW_MX_HS_CPG151101S11_1u
L_SW14: F; SW_MX_HS_CPG151101S11_1u
L_SW15: G; SW_MX_HS_CPG151101S11_1u
L_SW20: Shift; SW_MX_HS_CPG151101S11_1.75u
L_SW21: Z; SW_MX_HS_CPG151101S11_1u
L_SW22: X; SW_MX_HS_CPG151101S11_1u
L_SW23: C; SW_MX_HS_CPG151101S11_1u
L_SW24: V; SW_MX_HS_CPG151101S11_1u
L_SW25: B; SW_MX_HS_CPG151101S11_1u
L_SW30: Ctrl; SW_MX_HS_CPG151101S11_1.25u
L_SW31: GUI; SW_MX_HS_CPG151101S11_1u
L_SW32: Alt; SW_MX_HS_CPG151101S11_1.25u
L_SW33: Space; SW_MX_HS_CPG151101S11_1u
L_TP1: USB_DP; TestPoint_THTPad_D1.5mm_Drill0.7mm
L_TP2: USB_DM; TestPoint_THTPad_D1.5mm_Drill0.7mm
L_U1: Raspberry Pi Pico; RPi_Pico_SMD_TH
L_U2: 74AHCT1G125; SOT-23-5
R_C1: 100nF; C_0603_1608Metric
R_C2, R_C3: 1uF; C_0603_1608Metric
R_D00, R_D01, R_D02, R_D03, R_D04, R_D05, R_D10, R_D11, R_D12, R_D13, R_D14, R_D15, R_D20, R_D21, R_D22, R_D23, R_D24, R_D30, R_D31, R_D32, R_D33: 1N4148W; D_SOD-123
R_G1: Logo_Gemini
R_J1: USB-C link; HRO-TYPE-C-31-M-12-Assembly
R_LED00, R_LED01, R_LED02, R_LED03, R_LED04, R_LED05, R_LED10, R_LED11, R_LED12, R_LED13, R_LED14, R_LED15, R_LED20, R_LED21, R_LED22, R_LED23, R_LED24, R_LED30, R_LED31, R_LED32, R_LED33: SK6812MINI-E; LED_SK6812MINI-E_3.2x2.8mm_P1.5mm_ReverseMount
R_ST_SW24: stab 2.0u; STAB_MX_2u
R_ST_SW30: stab 2.75u; STAB_MX_2.75u
R_SW00: Y; SW_MX_HS_CPG151101S11_1u
R_SW01: U; SW_MX_HS_CPG151101S11_1u
R_SW02: I; SW_MX_HS_CPG151101S11_1u
R_SW03: O; SW_MX_HS_CPG151101S11_1u
R_SW04: P; SW_MX_HS_CPG151101S11_1u
R_SW05: Bksp; SW_MX_HS_CPG151101S11_1.5u
R_SW10: H; SW_MX_HS_CPG151101S11_1u
R_SW11: J; SW_MX_HS_CPG151101S11_1u
R_SW12: K; SW_MX_HS_CPG151101S11_1u
R_SW13: L; SW_MX_HS_CPG151101S11_1u
R_SW14: ;; SW_MX_HS_CPG151101S11_1u
R_SW15: Enter; SW_MX_HS_CPG151101S11_1.25u
R_SW20: N; SW_MX_HS_CPG151101S11_1u
R_SW21: M; SW_MX_HS_CPG151101S11_1u
R_SW22: ,; SW_MX_HS_CPG151101S11_1u
R_SW23: .; SW_MX_HS_CPG151101S11_1u
R_SW24: Shift; SW_MX_HS_CPG151101S11_1u
R_SW30: Space; SW_MX_HS_CPG151101S11_1u
R_SW31: Fn; SW_MX_HS_CPG151101S11_1.25u
R_SW32: Alt; SW_MX_HS_CPG151101S11_1.25u
R_SW33: Ctrl; SW_MX_HS_CPG151101S11_1.25u
R_U1: MCP23017-E/SO; SOIC-28W_7.5x17.9mm_P1.27mm
R_U2: MCP1700-3302; SOT-23

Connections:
L_+3V3: L_R1.2, L_R2.2, L_U1.36
L_CC1: L_J2.4, L_R3.1
L_CC2: L_J2.9, L_R4.1
L_COL0: L_SW00.1, L_SW10.1, L_SW20.1, L_SW30.1, L_U1.9
L_COL1: L_SW01.1, L_SW11.1, L_SW21.1, L_SW31.1, L_U1.10
L_COL2: L_SW02.1, L_SW12.1, L_SW22.1, L_SW32.1, L_U1.11
L_COL3: L_SW03.1, L_SW13.1, L_SW23.1, L_SW33.1, L_U1.12
L_COL4: L_SW04.1, L_SW14.1, L_SW24.1, L_U1.14
L_COL5: L_SW05.1, L_SW15.1, L_SW25.1, L_U1.15
L_GND: L_J1.1, L_J1.12, L_J1.13, L_J2.1, L_J2.12, L_J2.13, L_LED00.3, L_LED01.3, L_LED02.3, L_LED03.3, L_LED04.3, L_LED05.3, L_LED10.3, L_LED11.3, L_LED12.3, L_LED13.3, L_LED14.3, L_LED15.3, L_LED20.3, L_LED21.3, L_LED22.3, L_LED23.3, L_LED24.3, L_LED25.3, L_LED30.3, L_LED31.3, L_LED32.3, L_LED33.3, L_R3.2, L_R4.2, L_U1.3, L_U1.8, L_U1.13, L_U1.18, L_U1.23, L_U1.28, L_U1.33, L_U1.38, L_U1.42, L_U2.1, L_U2.3
L_LED_CH00: L_LED00.4, L_U2.4
L_LED_CH01: L_LED00.2, L_LED01.4
L_LED_CH02: L_LED01.2, L_LED02.4
L_LED_CH03: L_LED02.2, L_LED03.4
L_LED_CH04: L_LED03.2, L_LED04.4
L_LED_CH05: L_LED04.2, L_LED05.4
L_LED_CH06: L_LED05.2, L_LED10.4
L_LED_CH07: L_LED10.2, L_LED11.4
L_LED_CH08: L_LED11.2, L_LED12.4
L_LED_CH09: L_LED12.2, L_LED13.4
L_LED_CH10: L_LED13.2, L_LED14.4
L_LED_CH11: L_LED14.2, L_LED15.4
L_LED_CH12: L_LED15.2, L_LED20.4
L_LED_CH13: L_LED20.2, L_LED21.4
L_LED_CH14: L_LED21.2, L_LED22.4
L_LED_CH15: L_LED22.2, L_LED23.4
L_LED_CH16: L_LED23.2, L_LED24.4
L_LED_CH17: L_LED24.2, L_LED25.4
L_LED_CH18: L_LED25.2, L_LED30.4
L_LED_CH19: L_LED30.2, L_LED31.4
L_LED_CH20: L_LED31.2, L_LED32.4
L_LED_CH21: L_LED32.2, L_LED33.4
L_LED_DATA: L_U1.21, L_U2.2
L_LED_LINK: L_J1.3, L_J1.4, L_J1.9, L_J1.10, L_LED33.2
L_N_SW00: L_D00.2, L_SW00.2
L_N_SW01: L_D01.2, L_SW01.2
L_N_SW02: L_D02.2, L_SW02.2
L_N_SW03: L_D03.2, L_SW03.2
L_N_SW04: L_D04.2, L_SW04.2
L_N_SW05: L_D05.2, L_SW05.2
L_N_SW10: L_D10.2, L_SW10.2
L_N_SW11: L_D11.2, L_SW11.2
L_N_SW12: L_D12.2, L_SW12.2
L_N_SW13: L_D13.2, L_SW13.2
L_N_SW14: L_D14.2, L_SW14.2
L_N_SW15: L_D15.2, L_SW15.2
L_N_SW20: L_D20.2, L_SW20.2
L_N_SW21: L_D21.2, L_SW21.2
L_N_SW22: L_D22.2, L_SW22.2
L_N_SW23: L_D23.2, L_SW23.2
L_N_SW24: L_D24.2, L_SW24.2
L_N_SW25: L_D25.2, L_SW25.2
L_N_SW30: L_D30.2, L_SW30.2
L_N_SW31: L_D31.2, L_SW31.2
L_N_SW32: L_D32.2, L_SW32.2
L_N_SW33: L_D33.2, L_SW33.2
L_ROW0: L_D00.1, L_D01.1, L_D02.1, L_D03.1, L_D04.1, L_D05.1, L_U1.4
L_ROW1: L_D10.1, L_D11.1, L_D12.1, L_D13.1, L_D14.1, L_D15.1, L_U1.5
L_ROW2: L_D20.1, L_D21.1, L_D22.1, L_D23.1, L_D24.1, L_D25.1, L_U1.6
L_ROW3: L_D30.1, L_D31.1, L_D32.1, L_D33.1, L_U1.7
L_SCL: L_J1.5, L_J1.8, L_R2.1, L_U1.2
L_SDA: L_J1.6, L_J1.7, L_R1.1, L_U1.1
L_USB_DM: L_J2.5, L_J2.8, L_TP2.1
L_USB_DP: L_J2.6, L_J2.7, L_TP1.1
L_VBUS_HOST: L_DV1.2, L_J2.2, L_J2.11
L_VSYS: L_DV1.1, L_J1.2, L_J1.11, L_LED00.1, L_LED01.1, L_LED02.1, L_LED03.1, L_LED04.1, L_LED05.1, L_LED10.1, L_LED11.1, L_LED12.1, L_LED13.1, L_LED14.1, L_LED15.1, L_LED20.1, L_LED21.1, L_LED22.1, L_LED23.1, L_LED24.1, L_LED25.1, L_LED30.1, L_LED31.1, L_LED32.1, L_LED33.1, L_U1.39, L_U2.5
R_+3V3: R_C1.1, R_C3.1, R_U1.9, R_U1.18, R_U2.3
R_COL0: R_SW00.1, R_SW10.1, R_SW20.1, R_SW30.1, R_U1.1
R_COL1: R_SW01.1, R_SW11.1, R_SW21.1, R_SW31.1, R_U1.2
R_COL2: R_SW02.1, R_SW12.1, R_SW22.1, R_SW32.1, R_U1.3
R_COL3: R_SW03.1, R_SW13.1, R_SW23.1, R_SW33.1, R_U1.4
R_COL4: R_SW04.1, R_SW14.1, R_SW24.1, R_U1.5
R_COL5: R_SW05.1, R_SW15.1, R_U1.6
R_GND: R_C1.2, R_C2.2, R_C3.2, R_J1.1, R_J1.12, R_J1.13, R_LED00.3, R_LED01.3, R_LED02.3, R_LED03.3, R_LED04.3, R_LED05.3, R_LED10.3, R_LED11.3, R_LED12.3, R_LED13.3, R_LED14.3, R_LED15.3, R_LED20.3, R_LED21.3, R_LED22.3, R_LED23.3, R_LED24.3, R_LED30.3, R_LED31.3, R_LED32.3, R_LED33.3, R_U1.10, R_U1.15, R_U1.16, R_U1.17, R_U2.1
R_LED_CH01: R_LED00.2, R_LED01.4
R_LED_CH02: R_LED01.2, R_LED02.4
R_LED_CH03: R_LED02.2, R_LED03.4
R_LED_CH04: R_LED03.2, R_LED04.4
R_LED_CH05: R_LED04.2, R_LED05.4
R_LED_CH06: R_LED05.2, R_LED10.4
R_LED_CH07: R_LED10.2, R_LED11.4
R_LED_CH08: R_LED11.2, R_LED12.4
R_LED_CH09: R_LED12.2, R_LED13.4
R_LED_CH10: R_LED13.2, R_LED14.4
R_LED_CH11: R_LED14.2, R_LED15.4
R_LED_CH12: R_LED15.2, R_LED20.4
R_LED_CH13: R_LED20.2, R_LED21.4
R_LED_CH14: R_LED21.2, R_LED22.4
R_LED_CH15: R_LED22.2, R_LED23.4
R_LED_CH16: R_LED23.2, R_LED24.4
R_LED_CH17: R_LED24.2, R_LED30.4
R_LED_CH18: R_LED30.2, R_LED31.4
R_LED_CH19: R_LED31.2, R_LED32.4
R_LED_CH20: R_LED32.2, R_LED33.4
R_LED_LINK: R_J1.3, R_J1.4, R_J1.9, R_J1.10, R_LED00.4
R_N_SW00: R_D00.2, R_SW00.2
R_N_SW01: R_D01.2, R_SW01.2
R_N_SW02: R_D02.2, R_SW02.2
R_N_SW03: R_D03.2, R_SW03.2
R_N_SW04: R_D04.2, R_SW04.2
R_N_SW05: R_D05.2, R_SW05.2
R_N_SW10: R_D10.2, R_SW10.2
R_N_SW11: R_D11.2, R_SW11.2
R_N_SW12: R_D12.2, R_SW12.2
R_N_SW13: R_D13.2, R_SW13.2
R_N_SW14: R_D14.2, R_SW14.2
R_N_SW15: R_D15.2, R_SW15.2
R_N_SW20: R_D20.2, R_SW20.2
R_N_SW21: R_D21.2, R_SW21.2
R_N_SW22: R_D22.2, R_SW22.2
R_N_SW23: R_D23.2, R_SW23.2
R_N_SW24: R_D24.2, R_SW24.2
R_N_SW30: R_D30.2, R_SW30.2
R_N_SW31: R_D31.2, R_SW31.2
R_N_SW32: R_D32.2, R_SW32.2
R_N_SW33: R_D33.2, R_SW33.2
R_ROW0: R_D00.1, R_D01.1, R_D02.1, R_D03.1, R_D04.1, R_D05.1, R_U1.21
R_ROW1: R_D10.1, R_D11.1, R_D12.1, R_D13.1, R_D14.1, R_D15.1, R_U1.22
R_ROW2: R_D20.1, R_D21.1, R_D22.1, R_D23.1, R_D24.1, R_U1.23
R_ROW3: R_D30.1, R_D31.1, R_D32.1, R_D33.1, R_U1.24
R_SCL: R_J1.5, R_J1.8, R_U1.12
R_SDA: R_J1.6, R_J1.7, R_U1.13
R_VSYS: R_C2.1, R_J1.2, R_J1.11, R_LED00.1, R_LED01.1, R_LED02.1, R_LED03.1, R_LED04.1, R_LED05.1, R_LED10.1, R_LED11.1, R_LED12.1, R_LED13.1, R_LED14.1, R_LED15.1, R_LED20.1, R_LED21.1, R_LED22.1, R_LED23.1, R_LED24.1, R_LED30.1, R_LED31.1, R_LED32.1, R_LED33.1, R_U2.2

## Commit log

2026-08-02 3d renders
    [gemini-left.kicad_pcb, gemini-right.kicad_pcb, gemini_left_outline.csv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]
2026-08-02 add LEDs
    [gemini-left.kicad_pcb, gemini-right.kicad_pcb]
2026-08-02 add usb c
    [gemini-left.kicad_pcb, gemini-right.kicad_pcb]
2026-08-02 move usb c to the left
    [gemini-left.kicad_pcb, gemini-right.kicad_pcb]
2026-08-02 add case to docs
    [gemini_left_assembly.step, gemini_left_bottom.step, gemini_left_bottom.stl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]
2026-08-02 add frontplate browline cover, add joining wall edges
    [gemini-left.kicad_pcb, gemini-right.kicad_pcb, gemini_left_assembly.step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]
2026-08-05 a bunch of fixes
    [gemini-left.kicad_pcb, gemini-panel.kicad_pcb, gemini-right.kicad_pcb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]
2026-08-08 add silkscreening, and layer visibility for model view
    [gemini-left.kicad_pcb, gemini-panel.kicad_pcb, gemini-right.kicad_pcb]
